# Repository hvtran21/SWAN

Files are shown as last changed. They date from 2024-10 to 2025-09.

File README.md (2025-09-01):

# Secure Wireless Authentication Network (SWAN) Electrical & Computer Engineering Class of 2025

## Overview
**SWAN (Secure Wireless Authentication Network)** is a senior capstone project focused on developing a safer, more seamless alternative to traditional RFID and NFC-based access systems.  

Current wireless access solutions, such as student ID cards or key fobs, suffer from two major issues:
1. **Security vulnerabilities** – Devices such as the Flipper Zero can easily clone, replay, or brute-force RFID/NFC signals, compromising access control systems.  
2. **Limited usability** – Cards must be presented within a few centimeters of a scanner, which is inconvenient when carrying items (e.g., food, books, bags) and detracts from user experience.

SWAN leverages **Ultra-Wideband (UWB) technology** to deliver both stronger security and automatic, hands-free authentication.  

---

## Problem Statement
Existing RFID and NFC access systems are vulnerable and inconvenient:
- **Vulnerabilities**: RFID/NFC cards transmit predictable signals that can be intercepted and cloned.  
- **User experience**: Scanning requires close proximity, forcing users to stop what they’re doing to present their ID.  

This is especially problematic in settings like dormitories or offices where secure yet convenient access is critical.

---

## Solution
SWAN provides an **automatic, secure, and user-friendly wireless authentication system** powered by **UWB**.  

Key design features:
- **Hardware**:  
  - Custom-designed PCBs  
  - **ESP32-C3 WROOM** microcontroller  
  - **Decawave DWM3000 UWB transceiver**  
- **Architecture**:  
  - A distributed network of devices with a **home anchor** that verifies access  
  - Automatic authentication within a defined UWB range (no card-swipe required)  
- **Security**:  
  - Communication encrypted using **AES-128**, the standard for low-power embedded devices  
  - Resistant to replay and cloning attacks compared to RFID/NFC
  - Back method to lost tags which includes an optical finger print reader, independent from the anchor removing depedency.
 
### What this enables
The idea is that these `tag` devices can take space in your wallet as a card, and something on your keychain.
These are items that you typically always have on your person, and want to keep import track of. In the unfortunate event 
that one of these devices are stolen, rest assured you're provided with a back biometric feature and that **two** tags 
must be present at all times.

---

## Benefits
- **Improved security**: Protects against Flipper Zero-style exploits and unauthorized duplication.  
- **Hands-free access**: Users can enter secured areas automatically, without swiping or tapping a card.  
- **Energy-efficient**: Designed with low-power embedded constraints in mind.  
- **Scalable**: Can be deployed in dorms, offices, or any facility requiring secure access.  

---

## Technology Stack
- **Embedded Hardware**: ESP32-C3 WROOM, DWM3000 UWB  
- **Firmware**: C/C++ with ESP-IDF and Arduino frameworks  
- **Networking**: UWB communication protocol, AES-128 encryption  
- **Custom PCBs**: Designed for modularity and integration with door access hardware

---

# Pictures

## Tag PCB v3


## Home Anchor PCB v1


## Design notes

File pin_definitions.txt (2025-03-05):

----- PCB v1 -----
#define SPI_IRQ 4

#define SPI_CLK 5
#define SPI_MISO 6
#define SPI_MOSI 7
#define SPI_CSN 8

#define SPI_RST 9

----- PCB v2 -----
#define SPI_IRQ 18

#define SPI_CLK 7
#define SPI_MISO 6
#define SPI_MOSI 5
#define SPI_CSN 4

#define SPI_RST 19

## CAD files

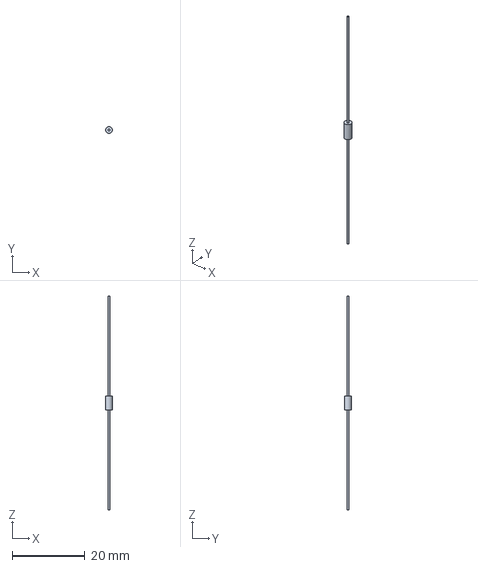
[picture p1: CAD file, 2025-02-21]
component_files/diode_files/1N4150.step
1.90 x 1.90 x 58.9 mm

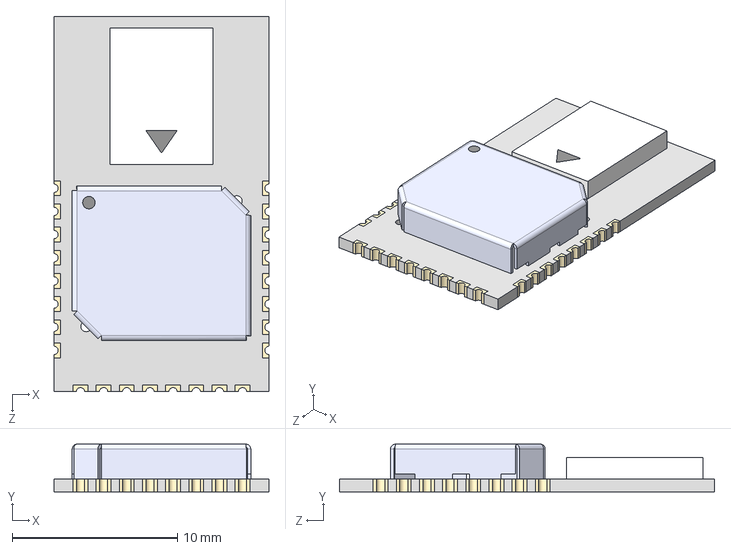
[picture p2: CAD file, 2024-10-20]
component_files/DWM3000_files/dwm3000_footprint/DWM3000TR13.step
13.0 x 2.89 x 22.7 mm

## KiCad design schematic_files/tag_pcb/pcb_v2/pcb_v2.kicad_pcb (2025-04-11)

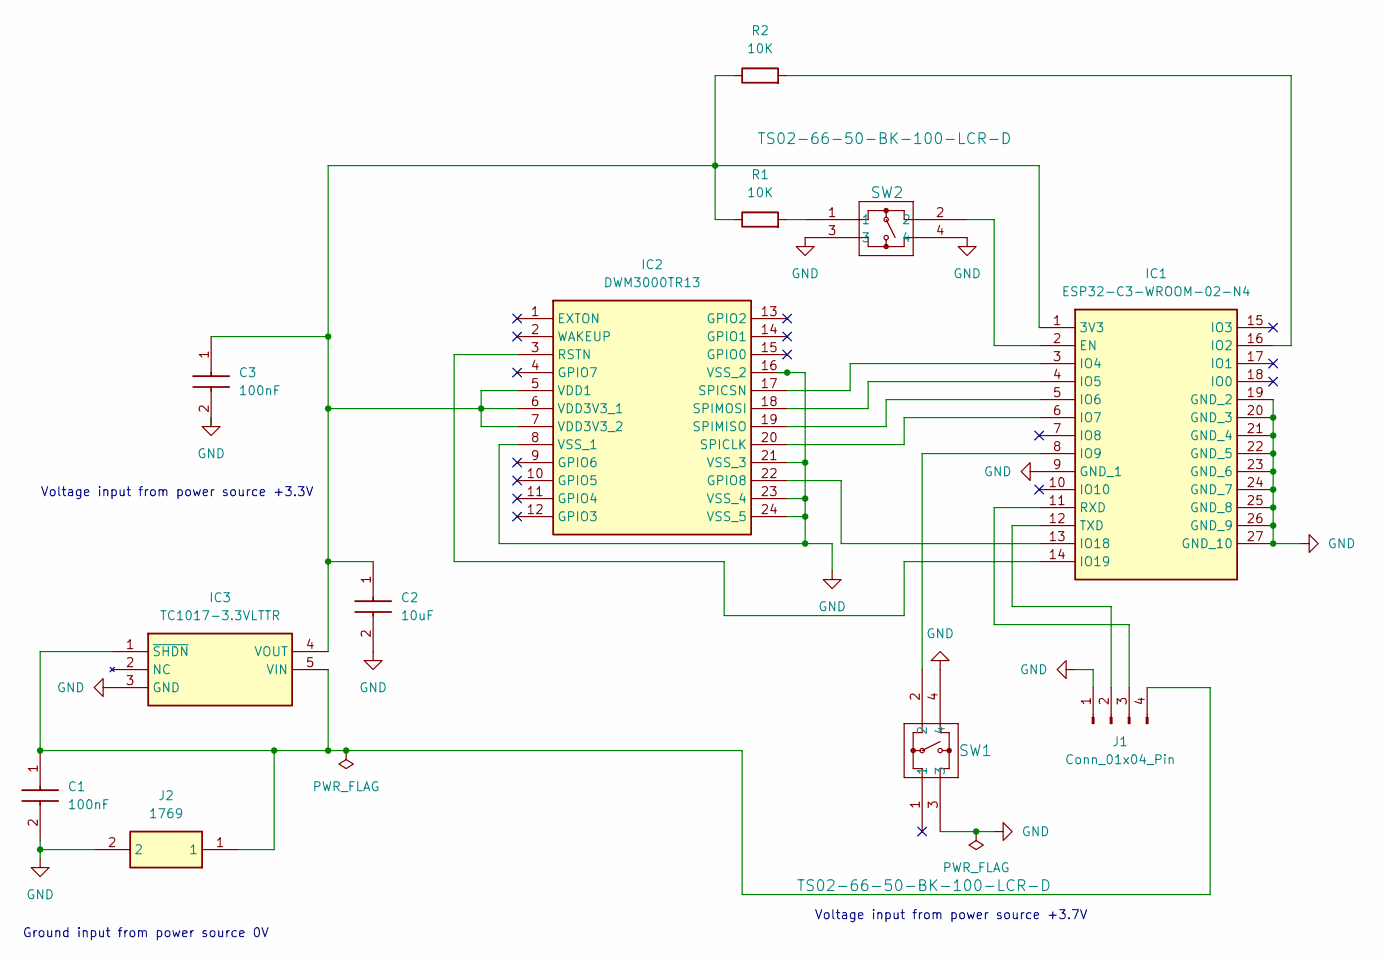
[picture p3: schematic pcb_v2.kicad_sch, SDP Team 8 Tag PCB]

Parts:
C1, C3: 100nF; CAPC2012X94N; Mouser Part Number 581-KAM21BR71H104JT
C2: 10uF; CAPC2012X140N; Mouser Part Number 81-GCM21BD70J106KE2L
IC1: ESP32-C3-WROOM-02-N4; ESP32C3WROOM02N4; Mouser Part Number 356-ESP32C3WROOM02N4
IC2: DWM3000TR13; XCVR_DWM3000TR13; Mouser Part Number 772-DWM3000TR13
IC3: TC1017-3.3VLTTR; SOT65P210X110-5N; Mouser Part Number 579-TC1017-3.3VLTTR
J1: Conn_01x04_Pin; PinHeader_1x04_P2.54mm_Vertical
J2: 1769; Mouser Part Number 485-1769
R1, R2: 10K; RESC3216X65N
SW1, SW2: TS02-66-50-BK-100-LCR-D; 6mm_push_button_footprint

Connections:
GND: C1.2, C2.2, C3.2, IC1.9 (GND_1), IC1.19 (GND_2), IC1.20 (GND_3), IC1.21 (GND_4), IC1.22 (GND_5), IC1.23 (GND_6), IC1.24 (GND_7), IC1.25 (GND_8), IC1.26 (GND_9), IC1.27 (GND_10), IC2.8 (VSS_1), IC2.16 (VSS_2), IC2.21 (VSS_3), IC2.23 (VSS_4), IC2.24 (VSS_5), IC3.3 (GND), J1.1, J2.2, SW1.3, SW1.4, SW2.3, SW2.4
unnamed: C2.1, C3.1, IC1.1 (3V3), IC2.5 (VDD1), IC2.6 (VDD3V3_1), IC2.7 (VDD3V3_2), IC3.4 (VOUT), R1.1, R2.1
unnamed: IC1.2 (EN), SW2.2
unnamed: IC1.16 (IO2), R2.2
unnamed: IC1.3 (IO4), IC2.17 (SPICSN)
unnamed: IC1.4 (IO5), IC2.18 (SPIMOSI)
unnamed: IC1.5 (IO6), IC2.19 (SPIMISO)
unnamed: IC1.6 (IO7), IC2.20 (SPICLK)
unnamed: IC1.8 (IO9), SW1.2
unnamed: IC1.13 (IO18), IC2.22 (GPIO8)
unnamed: IC1.14 (IO19), IC2.3 (RSTN)
unnamed: IC1.11 (RXD), J1.3
unnamed: IC1.12 (TXD), J1.2
unnamed: C1.1, IC3.1 (~SHDN), IC3.5 (VIN), J1.4, J2.1
unnamed: R1.2, SW2.1

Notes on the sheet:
Ground input from power source 0V
Voltage input from power source +3.7V
Voltage input from power source +3.3V

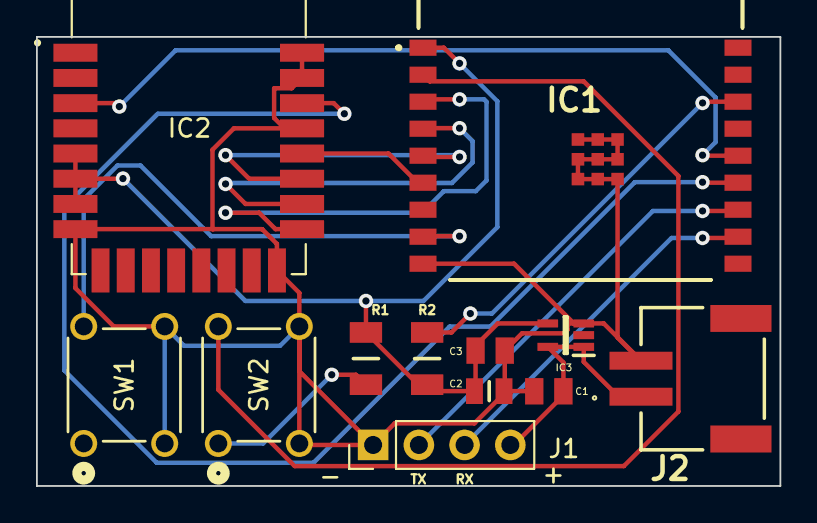
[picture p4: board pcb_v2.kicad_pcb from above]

Board: 2 copper layers, 41.3 x 24.9 mm, 12 parts (0 on the bottom side), 15 nets.

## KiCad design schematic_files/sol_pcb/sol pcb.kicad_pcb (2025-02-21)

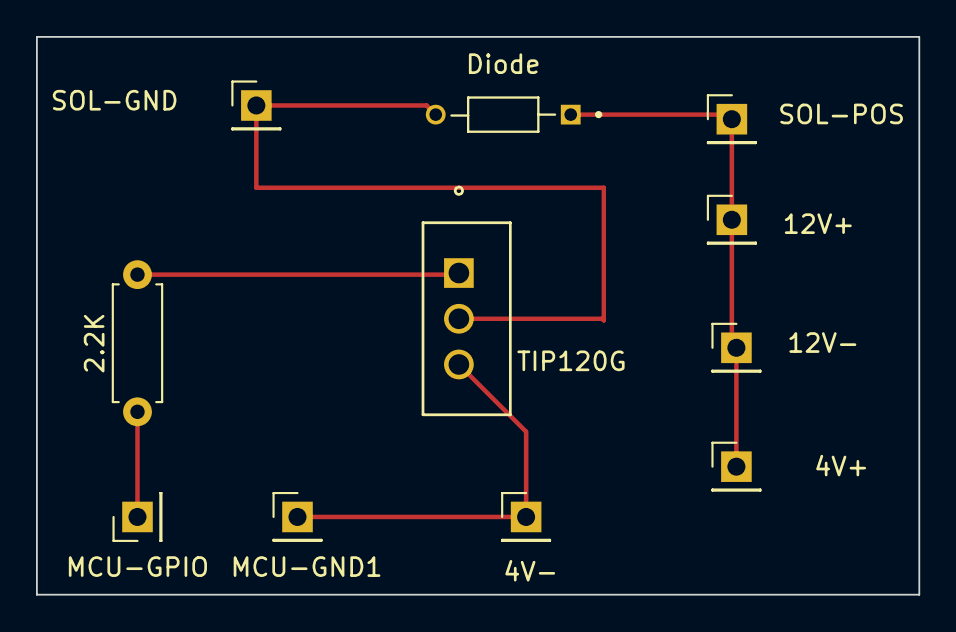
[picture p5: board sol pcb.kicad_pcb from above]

Board: 2 copper layers, 49.0 x 31.0 mm, 11 parts (0 on the bottom side), 5 nets.

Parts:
2.2K: R; R_Axial_DIN0207_L6.3mm_D2.5mm_P7.62mm_Horizontal
4V+, 4V-, 12V+, 12V-: Conn_01x01_Pin; PinHeader_1x01_P2.54mm_Vertical
Diode: 1N4150; DIOAD750W50L390D190
MCU-GND1: Conn_01x01_Pin; PinHeader_1x01_P2.54mm_Vertical
MCU-GPIO: Conn_01x01_Pin; PinHeader_1x01_P2.54mm_Vertical
SOL-GND: Conn_01x01_Pin; PinHeader_1x01_P2.54mm_Vertical
SOL-POS: Conn_01x01_Pin; PinHeader_1x01_P2.54mm_Vertical
TIP120G: TIP120G; TO-220_STM

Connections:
GND: 4V-.1, MCU-GND1.1, TIP120G.3 (E)
unnamed: 4V+.1, 12V+.1, 12V-.1, Diode.1, SOL-POS.1
unnamed: 2.2K.1, MCU-GPIO.1
unnamed: 2.2K.2, TIP120G.1 (B)
unnamed: Diode.2, SOL-GND.1, TIP120G.2 (C)

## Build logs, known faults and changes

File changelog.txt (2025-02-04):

Changes made so far for PCB v2 (as of 2/4/2025)

pin changes:
    CSN -> IO4
    MOSI -> IO5
    MISO -> IO6 
    CLK -> IO7
    RSTN -> IO19
    IRQ -> IO18

additions:
    - SW1 is the BOOT button, this will GND IO9 (PIN 8)
        for flash mode
    - SW2 is the RST button. Before we had to power cycle the 
        system which was inefficient, so this switch will ground it
    - There's an extra 01x02 pin header for extra GPIO
    - Added pull up resistor for the EN pin

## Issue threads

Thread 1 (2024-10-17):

Find operating temperatures of each component

hvtran21, 2024-10-17:
The intention of these devices is to be typically stashed in the pocket of a user, and our body's themselves emit heat, in addition to the consumption of power producing heat. Also, need to be wary of humid environments.

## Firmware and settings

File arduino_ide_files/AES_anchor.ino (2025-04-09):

#include "dw3000.h"
#include "dw3000_mac_802_15_4.h"
#include "esp_efuse.h"
#include "SPI.h"

#define APP_NAME "SS TWR AES INIT v1.0"

#define SPI_IRQ 18

#define SPI_CLK 7
#define SPI_MISO 6
#define SPI_MOSI 5
#define SPI_CSN 4

#define SPI_RST 19

#define VERIFIED_PIN 10
#define wait_lock 5000 // defines how long the lock is unlocked in ms (5s = 5000ms)

#define U64_TO_BYTES(val) \
  (uint8_t)((val) >> 56), \
  (uint8_t)((val) >> 48), \
  (uint8_t)((val) >> 40), \
  (uint8_t)((val) >> 32), \
  (uint8_t)((val) >> 24), \
  (uint8_t)((val) >> 16), \
  (uint8_t)((val) >> 8),  \
  (uint8_t)(val)

/* Sample of 802_15_4 frame*/
#if 0
mac_frame_802_15_4_format_t     mac_frame=
{
    /*
    * Frame control[0] = 0x09 = Data frame, security enabled, PEND not set, no ACK required, PANID compression set to zero (no PANID for source)
    * Frame control[1] = 0xEC = With seq num, no IEs, using extended address, frame ver 2 (IEEE Std 802.15.4)
    */
    .mhr_802_15_4.frame_ctrl[0]=0x09,
    .mhr_802_15_4.frame_ctrl[1]=0xEC,

    /* Sequence number initialize value*/
    .mhr_802_15_4.sequence_num=0x00,

    .mhr_802_15_4.dest_pan_id[0]=0x21,
    .mhr_802_15_4.dest_pan_id[1]=0x43,


    /* Set the Security Control field in the Auxiliary Security Header
    *  Security Control = 0xF:
    *                         Security level: 0x7 = MIC 16 (data confidentiality OFF, data authenticity Yes),
    *                         Key Identifier Mode: 0x1 = key determined from key index field,
    *                         Frame Counter Suppression: 0x0 = has the frame counter and the frame counter generates the nonce.
    *                         ASN in Nonce: 0x0 = frame counter is used to generate the nonce (CCM* nonce = SRC ADDR (8), Frame Counter (4) and Nonce Security Level (1) - set to 0x7 above)
    *  This means that format of the AUX header is Security Control (1 octet) + Fame Counter (4 octets) + Key Identifier (1 octet) = 6 octets
    */
    .mhr_802_15_4.aux_security.security_ctrl=0x0F,

};
mac_frame_802_15_4_format_t     mac_frame_2=
{
    /*
    * Frame control[0] = 0x09 = Data frame, security enabled, PEND not set, no ACK required, PANID compression set to zero (no PANID for source)
    * Frame control[1] = 0xEC = With seq num, no IEs, using extended address, frame ver 2 (IEEE Std 802.15.4)
    */
    .mhr_802_15_4.frame_ctrl[0]=0x09,
    .mhr_802_15_4.frame_ctrl[1]=0xEC,

    /* Sequence number initialize value*/
    .mhr_802_15_4.sequence_num=0x00,

    .mhr_802_15_4.dest_pan_id[0]=0x34,
    .mhr_802_15_4.dest_pan_id[1]=0x12,


    /* Set the Security Control field in the Auxiliary Security Header
    *  Security Control = 0xF:
    *                         Security level: 0x7 = MIC 16 (data confidentiality OFF, data authenticity Yes),
    *                         Key Identifier Mode: 0x1 = key determined from key index field,
    *                         Frame Counter Suppression: 0x0 = has the frame counter and the frame counter generates the nonce.
    *                         ASN in Nonce: 0x0 = frame counter is used to generate the nonce (CCM* nonce = SRC ADDR (8), Frame Counter (4) and Nonce Security Level (1) - set to 0x7 above)
    *  This means that format of the AUX header is Security Control (1 octet) + Fame Counter (4 octets) + Key Identifier (1 octet) = 6 octets
    */
    .mhr_802_15_4.aux_security.security_ctrl=0x0F,

};
#endif
mac_frame_802_15_4_format_t     mac_frame= {
  {
    {0x09, 0xEC},
    0x00,
    {0x21, 0x43},
    {0x00, 0x00, 0x00, 0x00, 0x00, 0x00, 0x00, 0x00},
    {0x00, 0x00, 0x00, 0x00, 0x00, 0x00, 0x00, 0x00},
    { 0x0F, {0x00, 0x00, 0x00, 0x00}, 0x00 }
  },
  0x00
};
mac_frame_802_15_4_format_t     mac_frame_2= {
  {
    {0x09, 0xEC},
    0x00,
    {0x21, 0x43},
    {0x00, 0x00, 0x00, 0x00, 0x00, 0x00, 0x00, 0x00},
    {0x00, 0x00, 0x00, 0x00, 0x00, 0x00, 0x00, 0x00},
    { 0x0F, {0x00, 0x00, 0x00, 0x00}, 0x00 }
  },
  0x00
};

#if 0
static dwt_aes_config_t aes_config=
{
    .key_load           = AES_KEY_Load,         // load the key into AES engine see Note 15 below
    .key_size           = AES_KEY_128bit,       // use 128bit key
    .key_src            = AES_KEY_Src_Register, // the key source is IC registers
    .aes_core_type      = AES_core_type_CCM,    // Use CCM core
    .aes_key_otp_type   = AES_key_RAM,
    .key_addr           = 0
};
static dwt_aes_config_t aes_config_2=
{
    .key_load           = AES_KEY_Load,         // load the key into AES engine see Note 15 below
    .key_size           = AES_KEY_128bit,       // use 128bit key
    .key_src            = AES_KEY_Src_Register, // the key source is IC registers
    .aes_core_type      = AES_core_type_CCM,    // Use CCM core
    .aes_key_otp_type   = AES_key_RAM,
    .key_addr           = 0
};
#endif

static dwt_aes_config_t aes_config = {
  AES_key_RAM,
  AES_core_type_CCM,
  MIC_0,
  AES_KEY_Src_Register,
  AES_KEY_Load,
  0,
  AES_KEY_128bit,
  AES_Encrypt
};
static dwt_aes_config_t aes_config_2 = {
  AES_key_RAM,
  AES_core_type_CCM,
  MIC_0,
  AES_KEY_Src_Register,
  AES_KEY_Load,
  0,
  AES_KEY_128bit,
  AES_Encrypt
};

/* Initiator data */
#define SRC_ADDR        0x8877665544332211 /* this is the address of the initiator */
// tag 1 info
#define DEST_ADDR       0x1122334455667788 /* this is the address of the responder tag 1*/
#define DEST_PAN_ID     0x4321             /* this is the PAN ID used in this example tag 1*/
// tag 2 info
#define DEST_ADDR_2     0x1122334455667799 /* tag 2 */
#define DEST_PAN_ID_2   0x1234

uint8_t SRC_ADDR_ARR[8] = { U64_TO_BYTES(SRC_ADDR) };
/* Default communication configuration. We use default non-STS DW mode. */
static dwt_config_t config =
{
    5,               /* Channel number. */
    DWT_PLEN_128,    /* Preamble length. Used in TX only. */
    DWT_PAC8,        /* Preamble acquisition chunk size. Used in RX only. */
    9,               /* TX preamble code. Used in TX only. */
    9,               /* RX preamble code. Used in RX only. */
    1,               /* 0 to use standard 8 symbol SFD, 1 to use non-standard 8 symbol, 2 for non-standard 16 symbol SFD and 3 for 4z 8 symbol SDF type */
    DWT_BR_6M8,      /* Data rate. */
    DWT_PHRMODE_STD, /* PHY header mode. */
    DWT_PHRRATE_STD, /* PHY header rate. */
    (129 + 8 - 8),   /* SFD timeout (preamble length + 1 + SFD length - PAC size). Used in RX only. */
    DWT_STS_MODE_OFF, /* STS disabled */
    DWT_STS_LEN_64,/* STS length see allowed values in Enum dwt_sts_lengths_e */
    DWT_PDOA_M0      /* PDOA mode off */
};


/* Optional keys according to the key index - In AUX security header*/
static dwt_aes_key_t    keys_options[NUM_OF_KEY_OPTIONS]=
{
    {0x00010203, 0x04050607, 0x08090A0B, 0x0C0D0E0F, 0x00000000, 0x00000000, 0x00000000, 0x00000000},
    {0x11223344, 0x55667788, 0x99AABBCC, 0xDDEEFF00, 0x00000000, 0x00000000, 0x00000000, 0x00000000},
    {0xFFEEDDCC, 0xBBAA9988, 0x77665544, 0x33221100, 0x00000000, 0x00000000, 0x00000000, 0x00000000}
};
static dwt_aes_key_t    keys_options_2[NUM_OF_KEY_OPTIONS]=
{
    {0x00010203, 0x04050607, 0x08090A0B, 0x0C0D0E0F, 0x00000000, 0x00000000, 0x00000000, 0x00000000},
    {0x11223344, 0x55667788, 0x99AABBCC, 0xDDEEFF00, 0x00000000, 0x00000000, 0x00000000, 0x00000000},
    {0xFFEEDDCC, 0xBBAA9988, 0x77665544, 0x33221100, 0x00000000, 0x00000000, 0x00000000, 0x00000000}
};


/* Default antenna delay values for 64 MHz PRF. See NOTE 2 below. */
#define TX_ANT_DLY 16385
#define RX_ANT_DLY 16385

/* MAC payload data of the frames used in the ranging process. See NOTE 3 below. */
/* Poll message from the initiator to the responder */
static uint8_t tx_poll_msg[] = {'P','o','l','l',' ','m','e','s','s','a','g','e'};
/* Response message to the initiator. The first 8 bytes are used for Poll RX time and Response TX time.*/
static uint8_t rx_resp_msg[] = {0,0,0,0,0,0,0,0,'R','e','s','p','o','n','s','e'};

/* Poll message from the initiator to the responder */
static uint8_t tx_poll_msg_2[] = {'T','e','s','t',' ','T','e','s','t','T','a','g'};
/* Response message to the initiator. The first 8 bytes are used for Poll RX time and Response TX time.*/
static uint8_t rx_resp_msg_2[] = {0,0,0,0,0,0,0,0,'T','e','s','t',' ','T','a','g'};

#define START_RECEIVE_DATA_LOCATION     8   //MAC payload user data starts at index 8 (e.g. 'R' - in above response message)

/* Indexes to access some of the fields in the frames defined above. */
#define ALL_MSG_SN_IDX 2            //sequence number byte index in MHR
#define RESP_MSG_POLL_RX_TS_IDX 0   //index in the MAC payload for Poll RX time
#define RESP_MSG_RESP_TX_TS_IDX 4   //index in the MAC payload for Response TX time
#define RESP_MSG_POLL_RX_TS_IDX_2 0   //index in the MAC payload for Poll RX time
#define RESP_MSG_RESP_TX_TS_IDX_2 4   //index in the MAC payload for Response TX time
#define RESP_MSG_TS_LEN 4

/* Note, the key index of 0 is forbidden to send as key index. Thus index 1 is the first.
 * This example uses this index for the key table for the encryption of initiator's data */
#define INITIATOR_KEY_INDEX     1

/* Buffer to store received response message.
 * Its size is adjusted to longest frame that this example code can handle. */
#define RX_BUF_LEN 127 /* The received frame cannot be bigger than 127 if STD PHR mode is used */
static uint8_t rx_buffer[RX_BUF_LEN];
static uint8_t rx_buffer_2[RX_BUF_LEN];

/* Delay between frames, in UWB microseconds. See NOTE 1 below. */
#define POLL_TX_TO_RESP_RX_DLY_UUS 1720
/* Receive response timeout. See NOTE 5 below. */
#define RESP_RX_TIMEOUT_UUS 250

/* Hold copies of computed time of flight and distance here for reference so that it can be examined at a debug breakpoint. */
static double tof;
static double tof_2;

/* Values for the PG_DELAY and TX_POWER registers reflect the bandwidth and power of the spectrum at the current
 * temperature. These values can be calibrated prior to taking reference measurements. See NOTE 2 below. */
extern dwt_txconfig_t txconfig_options;

static uint32_t   frame_cnt=0;  /* See Note 13 */
static uint8_t    seq_cnt=0x0A; /* Frame sequence number, incremented after each transmission. */
uint32_t          status_reg;
uint8_t           nonce[13];    /* 13-byte nonce used in this example as per IEEE802.15.4 */
uint8_t           nonce_2[13];    /* 13-byte nonce used in this example as per IEEE802.15.4 */
dwt_aes_job_t   aes_job_tx,aes_job_rx;
int8_t          status;

extern dwt_txconfig_t txconfig_options_2;

static uint32_t   frame_cnt_2=0;  /* See Note 13 */
static uint8_t    seq_cnt_2=0x0A; /* Frame sequence number, incremented after each transmission. */
uint32_t          status_reg_2;
dwt_aes_job_t   aes_job_tx_2,aes_job_rx_2;
int8_t          status_2;
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
void loop()
{
  tag_1_distance = get_distance();  // get distance from tag 1
  Sleep(TAG_REQUEST_DELAY_MS);
  tag_2_distance = get_distance_2(); // get distance from tag 2
  Sleep(TAG_REQUEST_DELAY_MS);
  
  Serial.print("tag 1: ");
  Serial.print(tag_1_distance); 
  Serial.print(" m");
  Serial.print(", tag 2: ");
  Serial.print(tag_2_distance);
  Serial.print(" m, ");

  if ((tag_1_distance != -1 or tag_2_distance != -1) and authenticated(tag_1_distance, tag_2_distance)) {
    Serial.print("Unlocking for 5 seconds ..\n");
    // unlock
    digitalWrite(VERIFIED_PIN, HIGH);
    // wait (5s)
    delay(wait_lock);
  } else {
    Serial.print("Locking .. \n");
    digitalWrite(VERIFIED_PIN, LOW);
  }
}

/*****************************************************************************************************************************************************
 * NOTES:
 *
 * 1. The single-sided two-way ranging scheme implemented here has to be considered carefully as the accuracy of the distance measured is highly
 *    sensitive to the clock offset error between the devices and the length of the response delay between frames. To achieve the best possible
 *    accuracy, this response delay must be kept as low as possible. In order to do so, 6.8 Mbps data rate is used in this example and the response
 *    delay between frames is defined as low as possible. The user is referred to User Manual for more details about the single-sided two-way ranging
 *    process.  NB:SEE ALSO NOTE 11.
 *
 *    Initiator: |Poll TX| ..... |Resp RX|
 *    Responder: |Poll RX| ..... |Resp TX|
 *                   ^|P RMARKER|                    - time of Poll TX/RX
 *                                   ^|R RMARKER|    - time of Resp TX/RX
 *
 *                       <--TDLY->                   - POLL_TX_TO_RESP_RX_DLY_UUS (RDLY-RLEN)
 *                               <-RLEN->            - RESP_RX_TIMEOUT_UUS   (length of response frame)
 *                    <----RDLY------>               - POLL_RX_TO_RESP_TX_DLY_UUS (depends on how quickly responder can turn around and reply)
 *
 *
 * 2. The sum of the values is the TX to RX antenna delay, this should be experimentally determined by a calibration process. Here we use a hard coded
 *    value (expected to be a little low so a positive error will be seen on the resultant distance estimate. For a real production application, each
 *    device should have its own antenna delay properly calibrated to get good precision when performing range measurements.
 * 3. The frames used here are Decawave specific ranging frames, complying with the IEEE 802.15.4 standard data frame encoding. The frames are the
 *    following:
 *     - a poll message sent by the initiator to trigger the ranging exchange.
 *     - a response message sent by the responder to complete the exchange and provide all information needed by the initiator to compute the
 *       time-of-flight (distance) estimate.
 *    The first 10 bytes of those frame are common and are composed of the following fields:
 *     - byte 0/1: frame control (0x8841 to indicate a data frame using 16-bit addressing).
 *     - byte 2: sequence number, incremented for each new frame.
 *     - byte 3/4: PAN ID (0xDECA).
 *     - byte 5/6: destination address, see NOTE 4 below.
 *     - byte 7/8: source address, see NOTE 4 below.
 *     - byte 9: function code (specific values to indicate which message it is in the ranging process).
 *    The remaining bytes are specific to each message as follows:
 *    Poll message:
 *     - no more data
 *    Response message:
 *     - byte 0 -> 13: poll message reception timestamp.
 *     - byte 4 -> 17: response message transmission timestamp.
 *    All messages end with a 2-byte checksum automatically set by DW IC.
 * 4. Source and destination addresses are hard coded constants in this example to keep it simple but for a real product every device should have a
 *    unique ID. Here, 16-bit addressing is used to keep the messages as short as possible but, in an actual application, this should be done only
 *    after an exchange of specific messages used to define those short addresses for each device participating to the ranging exchange.
 * 5. This timeout is for complete reception of a frame, i.e. timeout duration must take into account the length of the expected frame. Here the value
 *    is arbitrary but chosen large enough to make sure that there is enough time to receive the complete response frame sent by the responder at the
 *    6.8M data rate used (around 200 �s).
 * 6. In a real application, for optimum performance within regulatory limits, it may be necessary to set TX pulse bandwidth and TX power, (using
 *    the dwt_configuretxrf API call) to per device calibrated values saved in the target system or the DW IC OTP memory.
 * 7. dwt_writetxdata() takes the full size of the message as a parameter but only copies (size - 2) bytes as the check-sum at the end of the frame is
 *    automatically appended by the DW IC. This means that our variable could be two bytes shorter without losing any data (but the sizeof would not
 *    work anymore then as we would still have to indicate the full length of the frame to dwt_writetxdata()).
 * 8. We use polled mode of operation here to keep the example as simple as possible but all status events can be used to generate interrupts. Please
 *    refer to DW IC User Manual for more details on "interrupts". It is also to be noted that STATUS register is 5 bytes long but, as the event we
 *    use are all in the first bytes of the register, we can use the simple dwt_read32bitreg() API call to access it instead of reading the whole 5
 *    bytes.
 * 9. The high order byte of each 40-bit time-stamps is discarded here. This is acceptable as, on each device, those time-stamps are not separated by
 *    more than 2**32 device time units (which is around 67 ms) which means that the calculation of the round-trip delays can be handled by a 32-bit
 *    subtraction.
 * 10. The user is referred to DecaRanging ARM application (distributed with EVK1000 product) for additional practical example of usage, and to the
 *     DW IC API Guide for more details on the DW IC driver functions.
 * 11. The use of the clock offset value to correct the TOF calculation, significantly improves the result of the SS-TWR where the remote
 *     responder unit's clock is a number of PPM offset from the local initiator unit's clock.
 *     As stated in NOTE 2 a fixed offset in range will be seen unless the antenna delay is calibrated and set correctly.
 * 12. In this example, the DW IC is put into IDLE state after calling dwt_initialise(). This means that a fast SPI rate of up to 20 MHz can be used
 *     thereafter.
 * 13. Frame counter was set to zero in this example. The frame counter should be incremented each frame. When frame counter gets to its max value (uint32_t),
 *     key should be replaced.
 * 14. Desired configuration by user may be different to the current programmed configuration. dwt_configure is called to set desired
 *     configuration.
 * 15. When CCM core type is used, AES_KEY_Load needs to be set prior to each encryption/decryption operation, even if the AES KEY used has not changed.
 ****************************************************************************************************************************************************/

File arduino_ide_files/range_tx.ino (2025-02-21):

#include "dw3000.h"
#include "SPI.h"
#include "esp_efuse.h"
#define IS_TAG

extern SPISettings _fastSPI;

/* below are pin definitions for esp32-c3 development board */
// #define PIN_RST 8 
// #define PIN_IRQ 1
// #define PIN_SS 7
kjhsdfsdfgsdfg
/* below are pin definitions for esp32-c3 sdp pcb */
#define SPI_IRQ 4

#define SPI_CLK 5
#define SPI_MISO 6
#define SPI_MOSI 7
#define SPI_CSN 8

#define SPI_RST 9

#define TX_ANT_DLY 16385
#define RX_ANT_DLY 16385
#define ALL_MSG_COMMON_LEN 5
#define ALL_DATA_COMMON_LEN 2      // common first two bytes to recognize data transmission


#define ALL_MSG_SN_IDX 2
#define RESP_MSG_POLL_RX_TS_IDX 6
#define RESP_MSG_RESP_TX_TS_IDX 10
#define RESP_MSG_DATA_START_IDX 2  // index where data starts

#define POLL_RX_TO_RESP_TX_DLY_UUS 600

#define SIZE_OF_RX_BUFFER 20

/* Default communication configuration. We use default non-STS DW mode. */
static dwt_config_t config = {
    5,                /* Channel number. */
    DWT_PLEN_128,     /* Preamble length. Used in TX only. */
    DWT_PAC8,         /* Preamble acquisition chunk size. Used in RX only. */
    9,                /* TX preamble code. Used in TX only. */
    9,                /* RX preamble code. Used in RX only. */
    1,                /* 0 to use standard 8 symbol SFD, 1 to use non-standard 8 symbol, 2 for non-standard 16 symbol SFD and 3 for 4z 8 symbol SDF type */
    DWT_BR_6M8,       /* Data rate. */
    DWT_PHRMODE_STD,  /* PHY header mode. */
    DWT_PHRRATE_STD,  /* PHY header rate. */
    (129 + 8 - 8),    /* SFD timeout (preamble length + 1 + SFD length - PAC size). Used in RX only. */
    DWT_STS_MODE_OFF, /* STS disabled */
    DWT_STS_LEN_64,   /* STS length see allowed values in Enum dwt_sts_lengths_e */
    DWT_PDOA_M0       /* PDOA mode off */
};
static uint64_t unique_ID = ESP.getEfuseMac();
/* tag 1 */

// static uint8_t rx_poll_msg[] = {0x41, 0x88, 0, 0xCA, 0xDE, 0xE0, 0, 0, 0, 0, 0, 0};
// static uint8_t tx_resp_msg[] = {0x41, 0x88, 0, 0xCA, 0xDE, 0xE1, 0, 0, 0, 0, 0, 0, 0, 0, 0, 0, 0, 0};

// static uint8_t rx_data_poll_msg[] = {0xAA, 0xDD, 0, 0, 0, 0, 0, 0};
// static uint8_t tx_data_resp_msg[] = {0xAA, 0xCC, 0, 0, 0, 0, 0, 0, 0, 0, 0, 0, 0, 0, 0, 0, 0, 0, 0, 0, 0};

/* tag 2 */

static uint8_t rx_poll_msg[] = {0x09, 0x43, 0, 0xFE, 0xAA, 0xE0, 0, 0, 0, 0, 0, 0};
static uint8_t tx_resp_msg[] = {0x09, 0x43, 0, 0xFE, 0xAA, 0xE1, 0, 0, 0, 0, 0, 0, 0, 0, 0, 0, 0, 0};

static uint8_t rx_data_poll_msg[] = {0xCC, 0xAA, 0, 0, 0, 0, 0, 0};
static uint8_t tx_data_resp_msg[] = {0x02, 0x98, 0, 0, 0, 0, 0, 0, 0, 0, 0, 0, 0, 0, 0, 0, 0, 0, 0, 0, 0};

static uint8_t distance_frame_counter = 0;
static uint8_t data_frame_counter = 0;
static uint8_t rx_buffer[SIZE_OF_RX_BUFFER];
static uint32_t status_reg = 0;
static uint64_t poll_rx_ts;
static uint64_t resp_tx_ts;

extern dwt_txconfig_t txconfig_options;

void setup() {
  UART_init();

  _fastSPI = SPISettings(16000000L, MSBFIRST, SPI_MODE0);

  pinMode(SPI_IRQ, OUTPUT);
  
  SPI.begin(SPI_CLK, SPI_MISO, SPI_MOSI, SPI_CSN);
  spiSelect(SPI_CSN);  

  delay(2); // Time needed for DW3000 to start up (transition from INIT_RC to IDLE_RC, or could wait for SPIRDY event)

  while (!dwt_checkidlerc()) // Need to make sure DW IC is in IDLE_RC before proceeding
  {
    UART_puts("IDLE FAILED\r\n");
    while (1)
      ;
  }

  if (dwt_initialise(DWT_DW_INIT) == DWT_ERROR)
  {
    UART_puts("INIT FAILED\r\n");
    while (1)
      ;
  }

  // Enabling LEDs here for debug so that for each TX the D1 LED will flash on DW3000 red eval-shield boards.
  dwt_setleds(DWT_LEDS_ENABLE | DWT_LEDS_INIT_BLINK);

  /* Configure DW IC. See NOTE 6 below. */
  if (dwt_configure(&config)) // if the dwt_configure returns DWT_ERROR either the PLL or RX calibration has failed the host should reset the device
  {
    UART_puts("CONFIG FAILED\r\n");
    while (1)
      ;
  }

  /* Configure the TX spectrum parameters (power, PG delay and PG count) */
  dwt_configuretxrf(&txconfig_options);

  /* Apply default antenna delay value. See NOTE 2 below. */
  dwt_setrxantennadelay(RX_ANT_DLY);
  dwt_settxantennadelay(TX_ANT_DLY);

  /* Next can enable TX/RX states output on GPIOs 5 and 6 to help debug, and also TX/RX LEDs
   * Note, in real low power applications the LEDs should not be used. */
  dwt_setlnapamode(DWT_LNA_ENABLE | DWT_PA_ENABLE);

  for (int i = 0; i < SIZE_OF_RX_BUFFER; i++) {
    rx_buffer[i] = 0;
  }

  Serial.println("Range TX");
  Serial.println("Tag 2 set up...");
}

void send_distance() {
    /* Activate reception immediately. */
  dwt_rxenable(DWT_START_RX_IMMEDIATE);

  /* Poll for reception of a frame or error/timeout. See NOTE 6 below. */
  while (!((status_reg = dwt_read32bitreg(SYS_STATUS_ID)) & (SYS_STATUS_RXFCG_BIT_MASK | SYS_STATUS_ALL_RX_ERR)))
  {
  };

  if (status_reg & SYS_STATUS_RXFCG_BIT_MASK)
  {
    uint32_t frame_len;
    /* Clear good RX frame event in the DW IC status register. */
    dwt_write32bitreg(SYS_STATUS_ID, SYS_STATUS_RXFCG_BIT_MASK);

    /* A frame has been received, read it into the local buffer. */
    frame_len = dwt_read32bitreg(RX_FINFO_ID) & RXFLEN_MASK;
    if (frame_len <= sizeof(rx_buffer))
    {
      dwt_readrxdata(rx_buffer, frame_len, 0);

      /* Check that the frame is a poll sent by "SS TWR initiator" example.
       * As the sequence number field of the frame is not relevant, it is cleared to simplify the validation of the frame. */
      rx_buffer[ALL_MSG_SN_IDX] = 0;
      if (memcmp(rx_buffer, rx_poll_msg, ALL_MSG_COMMON_LEN) == 0)
      {
        uint32_t resp_tx_time;
        int ret;

        /* Retrieve poll reception timestamp. */
        poll_rx_ts = get_rx_timestamp_u64();

        /* Compute response message transmission time. See NOTE 7 below. */
        resp_tx_time = (poll_rx_ts + (POLL_RX_TO_RESP_TX_DLY_UUS * UUS_TO_DWT_TIME)) >> 8;
        dwt_setdelayedtrxtime(resp_tx_time);

        /* Response TX timestamp is the transmission time we programmed plus the antenna delay. */
        resp_tx_ts = (((uint64_t)(resp_tx_time & 0xFFFFFFFEUL)) << 8) + TX_ANT_DLY;

        /* Write all timestamps in the final message. See NOTE 8 below. */
        resp_msg_set_ts(&tx_resp_msg[RESP_MSG_POLL_RX_TS_IDX], poll_rx_ts);
        resp_msg_set_ts(&tx_resp_msg[RESP_MSG_RESP_TX_TS_IDX], resp_tx_ts); //resp_tx_ts is 64 bit, takes 8 slots in array

        /* Write and send the response message. See NOTE 9 below. */
        tx_resp_msg[ALL_MSG_SN_IDX] = distance_frame_counter;
        dwt_writetxdata(sizeof(tx_resp_msg), tx_resp_msg, 0); /* Zero offset in TX buffer. */
        dwt_writetxfctrl(sizeof(tx_resp_msg), 0, 1);          /* Zero offset in TX buffer, ranging. */
        ret = dwt_starttx(DWT_START_TX_DELAYED);
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

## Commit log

2024-10-17 initial commit; add pcb, schem and datasheets
    [Adafruit LIPoly Charger BFF.brd, Adafruit LIPoly Charger BFF.sch, Adafruit QT Py RP2040.brd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]
2024-10-20 add uwb kicad project files
    [UWB_PCB.kicad_pcb, UWB_PCB.kicad_sch]
2024-10-20 change name of uwb proj folder
    [UWB_PCB.kicad_pcb, UWB_PCB.kicad_sch]
2024-10-20 clean kicad file dir
    [uwb_prototype_pcb.kicad_pcb, uwb_prototype_pcb.kicad_sch]
2024-10-20 add uwb dwm3000 footprint files, located in dwm3000_footprint directory. add kicad project files, contains uwb schematic.
    [DWM3000TR13.step]
2024-10-24 add different schematic/pcb files for updated esp32 mcu
2024-10-24 move esp32 files to footprint dir for kicad use
2024-10-24 add new voltage regulator, since we need an LDO to regulate 3.7v to 3.3v
2024-10-24 first revision of swan pcb. note that this includes a horizontal 2x3 pinout for flashing code to the mcu. decided to move the powersource from battery completely off PCB, and perhaps is a seperate co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
    [pcb_v1.kicad_pcb, pcb_v1.kicad_sch]
2024-10-24 new kicad file was created in order to attempt to copy schematic files and symbols into a global library. moving away from these devices, ignore these files
    [Adafruit LIPoly Charger BFF.kicad_pcb, Adafruit LIPoly Charger BFF.kicad_sch, Adafruit QT Py RP2040.kicad_sch]
2024-10-24 uwb pcb autosave backups, not important.
2024-10-29 add schem files for capacitors and resistors, will be using smd componenets. added footprint assignments to pcb, so there will be changes there, but those footprint assignments are local. you must go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
    [pcb_v1.kicad_sch]
2024-10-29 move .*mod files to footprint directories for new schematic files
2024-10-29 update pcb with current schematic, assigned footprints to caps and res, didn't wire anything
    [pcb_v1.kicad_pcb, pcb_v1.kicad_sch]
2024-10-31 pcb edits. add led footprints
    [pcb_v1.kicad_pcb, pcb_v1.kicad_sch]
2024-10-31 update pin for jake baby
    [pcb_v1.kicad_pcb, pcb_v1.kicad_sch]
2024-11-06 files for esp32 development. added li poly charger connector to schematic build.
    [pcb_v1-B_Adhesive.gbr, pcb_v1-B_Courtyard.gbr, pcb_v1-B_Cu.gbr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]
2024-11-07 added a test hello_world project, which would connect and communicate to the esp32c3-wroom-02 chip (dev-board). there are pre-reqs in order to run this project, you need to install esp-idf VSC extens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
2024-11-07 move component files to a different directory to clean up the root directory
    [Adafruit LIPoly Charger BFF.brd, Adafruit LIPoly Charger BFF.kicad_pcb, Adafruit LIPoly Charger BFF.kicad_sch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]
2024-11-07 change mcu to esp32-c3-wroom, matches mcu on devboard kit.
2024-11-07 update pcb to use new mcu. the antennas are hanging off the pcb, and there are additional 1x4 pin headers for interfacing with unused GPIO pins just incase, and to flash code rx/tx.
    [pcb_v1.kicad_pcb, pcb_v1.kicad_sch]
2024-11-12 small changes to pcb, removed resistors and edited spi pins that connect mcu to uwb
    [pcb_v1.kicad_sch]
2024-11-21 fix wiring issue, EN pin on esp32 always grounded
    [pcb_v1.kicad_pcb]
2024-11-24 edit SPI configuration to work with custom PCB, and added config for GPIO port to switch to HIGH when tag is <= 1meter (rx)
2024-12-04 fix paste issue in tx
    [range_rx.ino, range_tx.ino]
2025-01-30 clean up repo. all kicad schematic files should be stored in schematic_files, and only include just the .kicad_sch and .kicad_pcb
    [pcb_v1-B_Adhesive.gbr, pcb_v1-B_Courtyard.gbr, pcb_v1-B_Cu.gbr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]
2025-02-03 add esp32 c3 datasheet
2025-02-03 add txt for pin assignment changes
2025-02-03 add push button schem and footprint
2025-02-04 add 10k footprint and symbol. Not using the symbol, just the footprint, but though to add it just in case.
2025-02-04 add kicad files. added pcb_v1 just for consistency. you must have the library files loaded in order for the project file to be opened with success
2025-02-04 add changelog.txt. This consists of changes to the PCB project. Stay updated on this since it will alleviate headaches later on
2025-02-12 update range_rx arduino to most recent revision
2025-02-21 add solenoid pcb
    [1N4150.step, sol pcb.kicad_pcb, sol pcb.kicad_sch]
2025-02-21 Move component files to correct directory
    [1N4150.step]
2025-02-21 Remove space in directory containing solenoid pcb. Added back silkscreen containing our group number
    [sol pcb-B_Cu.gbl, sol pcb-B_Mask.gbs, sol pcb-B_Paste.gbp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]
2025-02-21 Add .gbr and .drl files for JLCPCB
    [pcb_v2-B_Cu.gbl, pcb_v2-B_Mask.gbs, pcb_v2-B_Paste.gbp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]
2025-03-04 gbr .zip files added for pcb order
2025-03-04 add notes for power analysis
2025-03-04 add power analysis for tag
2025-03-05 add pin definitions txt due to varying SPI pin setups across different PCB versions
2025-03-27 add fingerprint.ino file; working now
2025-03-27 add pcb_v2 files
    [pcb_v2-B_Cu.gbl, pcb_v2-B_Mask.gbs, pcb_v2-B_Paste.gbp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]
2025-04-09 fix delay between when tags enter range to when anchor can recognize that. update file names to make it obvious what is what.
    [AES_anchor.ino, AES_tag.ino]
2025-04-11 update esp32 documentation file name
2025-04-11 add tag pcb kicad files. added tag .gbr files required for jlcpcb fab
    [pcb_v2.kicad_pcb, pcb_v2.kicad_sch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]
2025-04-22 Webserver ino files
    change const char *ssid and const char *password to switch wifi networks. Connect anchor TX to GPIO 4
